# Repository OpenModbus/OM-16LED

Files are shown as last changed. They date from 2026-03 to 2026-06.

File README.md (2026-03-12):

# Open Modbus OM-16LED









A compact industrial-grade **16-channel Modbus RTU LED driver module** featuring high-current MOSFET outputs, per-bank terminal grouping, wide load voltage range, DIN-rail support, and full configuration via Modbus holding registers. Designed for lighting automation, distributed I/O, and custom control applications.

## 1. Product Overview

The **Open Modbus OM-16LED** is a 16-channel low-side LED driver module intended for industrial automation, lighting control, and distributed I/O networks using **Modbus RTU** over RS-485.
It switches DC LED loads such as LED strips, architectural lighting, and indicator arrays up to **60 VDC** at up to **8 A per channel**.

The module combines an **STM32G474** microcontroller, eight **2EDN7534B** dual-channel low-side gate drivers, and sixteen **NTMFS4D0N08XT1G** N-channel power MOSFETs.
This architecture enables reliable, high-current, and scalable LED output control with built-in protection and per-channel MOSFET switching.

### 📦 Hardware Files

The full schematic and BOM are available at:

- Schematic → [https://github.com/OpenModbus/OM-16LED/blob/main/assets/schematics.pdf](https://github.com/OpenModbus/OM-16LED/blob/main/assets/schematics.pdf)
- BOM → [https://github.com/OpenModbus/OM-16LED/blob/main/assets/bom.csv](https://github.com/OpenModbus/OM-16LED/blob/main/assets/bom.csv)

Check the latest release for more!

## 2. Key Features

- 16 low-side MOSFET output channels
- Up to **8 A per channel**, **60 VDC** maximum load voltage
- **12 VDC** direct input or **15–27 VDC** via onboard converter (jumper selectable)
- RS-485 Modbus RTU communication (THVD1450 transceiver)
- Fully configurable serial parameters
- DEGSON 2EDGVC pluggable screw terminals
- DIN-rail mount using **UM72S profile**
- Compact PCB (100 × 72 mm)

## 3. Applications

Ideal for:

- LED strip lighting control
- Architectural and mood lighting
- Building automation
- PLC expansion
- Industrial signaling and indicators
- Stage and display lighting
- Custom distributed lighting networks

## 4. Hardware Architecture

### Microcontroller

The STM32G474RETx MCU handles Modbus RTU processing, configuration storage, and output control logic.
It is an ARM Cortex-M4 running at up to 170 MHz with 512 KB flash and 128 KB RAM, providing ample headroom for advanced output control features.

### Gate Drivers

Eight **2EDN7534B** (Infineon) dual-channel low-side gate drivers control the power MOSFETs.
Their key characteristics include:

- 2 channels per IC (8 ICs → 16 channels total)
- 5 A peak gate drive current
- Precise timing and low output resistance
- Designed for reliable switching of high-current loads

### Output MOSFETs

Sixteen **NTMFS4D0N08XT1G** (onsemi) N-channel MOSFETs perform the actual load switching.
Their key characteristics include:

- 80 V drain-source breakdown voltage
- High continuous drain current
- SO8FL package

### RS-485 Communication

A **THVD1450** (Texas Instruments) transceiver provides differential RS-485 communication with:

- ±18 kV IEC ESD protection
- Fail-safe features
- Suitable for long cable runs

### Power

The board supports two input modes selected by an onboard jumper:

- **15–27 VDC input** — passes through the **R-78E12-1.0** step-down regulator (RECOM), which generates the 12 V gate driver supply
- **12 VDC direct input** — bypasses the 12 V converter; 12 V is fed directly to the gate drivers

In both modes the **R-78E3.3-0.5** step-down regulator (RECOM) generates 3.3 V for the MCU and logic from the main input rail.

## 5. Electrical Specifications

### Supply

- **12 VDC** direct input (jumper: bypass mode) or **15–27 VDC** input (jumper: converter mode)
- Internal regulated **12 V gate drive** supply (converter mode only)
- Internal regulated **3.3 V logic** supply

### Outputs

- 16 low-side MOSFET channels
- Up to **60 VDC** load voltage
- 80 VDC absolute maximum
- **8 A max per channel**
- Channels grouped into **4 banks of 4**

### Communication

- RS-485, 2-wire
- Modbus RTU protocol
- Default settings: **9600 baud, 8N1, address 1**
- All communication parameters can be reconfigured via holding registers

## 6. Mechanical Information

- PCB: **100 × 72 mm**
- DIN-rail enclosure compatibility: **UM72S profile**
- DEGSON 2EDGVC pluggable screw terminals
- Mounting suitable for industrial control cabinets

## 7. Functional Overview

Each output channel is controlled by a per-channel duty cycle value stored in a holding register.
The MCU generates a PWM signal accordingly, driving the gate driver and MOSFET to regulate LED brightness.
A duty cycle of **0** turns the channel fully off; the maximum value drives it fully on.

## 8. Modbus Interface

### Supported Function Codes

> **To be announced soon.**

### Holding Registers

Configuration registers start at **0x00** and are stored in non-volatile memory.

| Register Address (Hex) | Name | Description | Allowed Values | Default |
|---|---|---|---|---|
| 0 (**0x00**) | Slave Address  | Modbus device ID | 1–247 | 1 |
| 1 (**0x01**) | Baud Rate Code | Serial speed selector: **0=1200**, **1=2400**, **2=4800**, **3=9600**, **4=19200**, **5=38400**, **6=57600**, **7=115200** | 0–7 | 3 |
| 2 (**0x02**) | Parity | Communication parity | 0=None, 1=Even, 2=Odd | 0 |
| 3 (**0x03**) | Data Bits | Serial data width | 5–9 (typ. 8) | 8 |
| 4 (**0x04**) | Stop Bits | Serial stop bits | 1–2 | 1 |

### Example Modbus Commands

> **To be announced soon.**

## 9. Wiring

The **OM-16LED** uses low-side (MOSFET) switching.
The module connects the LED load to ground when ON; the load must be powered from your external power supply.

The 16 outputs are grouped into **four banks of 4 channels** (Bank A–D).
This allows one board to drive LED loads powered from different voltages simultaneously.

**Examples**:

- Bank A → 12 V LED strips
- Bank B → 24 V LED strips
- Bank C → 48 V LED channels
- Bank D → 5 V LED indicators

### Low-Side Output Principle

Each output contains a power MOSFET that sinks current:

```text
Load +V  ─────── LED Load ─────── OUTx (SINK)
                                       │
                                       └── GND (OM-16LED)
```

### Recommended Wiring Steps

- Connect the load voltage (up to 60 VDC) to the Vx terminal of the bank.
- Connect the output pin (OUTx) to the negative side of the LED load.
- Tie power supply GND to OM-16LED GND.
- Ensure the supply can support the total current of that bank.

**⚠️ Important Grounding Requirement**:
All load power supplies must share **a common ground** with the OM-16LED.
This is required for the low-side drivers and internal logic to reference the same electrical 0 V.

## 10. Safety Notes

- Do not exceed **60 VDC** load voltage
- Ensure load currents stay within **8 A per channel**
- Maintain proper RS-485 termination and shielding
- Verify adequate heat dissipation when operating at high currents

## 11. Contact & Support

For questions, feedback, or technical assistance regarding the Open Modbus OM-16LED, the following support channels are available:

### 📧 Email Support

For general inquiries, firmware questions, or troubleshooting:
[contact@sszczep.dev](mailto:contact@sszczep.dev)

### 🛠 GitHub Repository

Issue tracker, source code, hardware design files, and community contributions:
[https://github.com/OpenModbus/OM-16LED](https://github.com/OpenModbus/OM-16LED)

### 💬 Open Modbus Discussions

Share projects, ask for help, or suggest features:
[https://github.com/orgs/OpenModbus/discussions](https://github.com/orgs/OpenModbus/discussions)

### 📝 Bug Reports & Feature Requests

Submit issues directly via GitHub Issues:
[https://github.com/OpenModbus/OM-16LED/issues](https://github.com/OpenModbus/OM-16LED/issues)

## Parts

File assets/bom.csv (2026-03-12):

Reference | Value | Footprint | Datasheet | Opis | Qty | Manufacturer | Mouser# | Part Number | LCSC#
C1,C2,C3,C4,C5,C6,C7,C8 | 0.1uF | C_0805_2012Metric | ~ | 0.1 uF 50 VDC 10% 0805 X7R AEC-Q200 | 8 | Murata | 81-GRT21BR71H104KE1L | GRT21BR71H104KE01L | C782178
C13 | 4.7uF | C_0603_1608Metric | ~ | 4.7 uF 25 VDC 10% 0603 X5R | 1 | Murata | 81-GRM188R61E475KE1D | GRM188R61E475KE11D | C90057
C14,C15,C16,C17,C19,C22,C23 | 0.1uF | C_0603_1608Metric | ~ | 0.1 uF 50 VDC 10% 0603 X7R AEC-Q200 | 7 | Murata | 81-GCJ188R71H104KA2D | GCJ188R71H104KA12D | C161115
C18,C21 | 1uF | C_0603_1608Metric | ~ | 1 uF 50 VDC 10% 0603 X5R AEC-Q200 | 2 | Murata | 81-GRT188R61H105KE3D | GRT188R61H105KE13D | C126631
C20 | 10nF | C_0603_1608Metric | ~ | 0.01 uF 50 VDC 10% 0603 X7R AEC-Q200 | 1 | Murata | 81-GCM188R71H103KA7D | GCM188R71H103KA37D | C85863
C9,C10,C11,C12 | 10uF | C_1206_3216Metric | ~ | 10 uF 50 VDC 10% 1206 X5R AEC-Q200 | 4 | Murata | 81-GRT31CR61H106KE1L | GRT31CR61H106KE01L | C417124
D1 | CD123D-B140LR | D_SOD-123 | https://www.mouser.com/catalog/specsheets/bourns_CD123D-B1xR.pdf | Schottky diode, small symbol | 1 | Bourns | 652-CD123D-B140LR | CD123D-B140LR | C6877135
D2 | SMAJ28A | D_SMA | https://www.littelfuse.com/media?itemid=75e32973-b177-4ee3-a0ff-cedaf1abdb93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 | 400W unidirectional Transient Voltage Suppressor, 28.0Vr, SMA(DO-214AC) | 1 | Littelfuse | 576-SMAJ28A | SMAJ28A | C148227
D3 | SM712_SOT23 | SOT-23 | https://www.littelfuse.com/~/media/electronics/datasheets/tvs_diode_arrays/littelfuse_tvs_diode_array_sm712_datasheet.pdf.pdf | 7V/12V, 600W Asymmetrical TVS Diode Array, SOT-23 | 1 | Littelfuse | 576-SM712-02HTG | SM712-02HTG | C172881
D4,D5 | RED | LED_0603_1608Metric | ~ | Single Color LEDs Red Clear 621nm | 2 | LITEON | 859-LTST-C190EKT | LTST-C190EKT | C364560
F1,F2,F3,F4,F5,F6,F7,F8,F9,F10,F11,F12,F13,F14,F15,F16 | 8A 60VDC | Fuse_0679H | https://www.belfuse.com/media/datasheets/products/circuit-protection/ds-cp-0679h-series.pdf | Surface Mount Fuse 8A 350 VAC 72 VCD | 16 | Bel Fuse | 530-0679H8000-05 | 0679H8000-05 | C3156889
F17 | 1A | Fuse_1206_3216Metric | https://www.littelfuse.com/assetdocs/littelfuse_fuse_466_datasheet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 | Surface Mount Fuse 63V FA 1206 1A VFA Slimline | 1 | Littelfuse | 576-0466001.NR | 0466001.NR | C151135
J1 | 2EDGVC-5.0-04P | TerminalBlock_DEGSON_2EDGVC-5.0-04P_No_SilkScreen |  |  | 1 | DEGSON |  | 10030002303 | C441377
J2,J3,J4,J5 | 2EDGVC-5.0-06P | TerminalBlock_DEGSON_2EDGVC-5.0-06P_No_SilkScreen |  |  | 4 | DEGSON |  | 10030002306 | C441379
J6 | 02x03 1.27 | PinHeader_2x03_P1.27mm_Vertical | ~ | Generic connector, double row, 02x03, odd/even pin numbering scheme (row 1 odd numbers, row 2 even numbers), script generated (kicad-library-utils/schlib/autogen/connector/) | 1
Q1,Q2,Q3,Q4,Q5,Q6,Q7,Q8,Q9,Q10,Q11,Q12,Q13,Q14,Q15,Q16 | NTMFS4D0N08X | ONSemi_SO-8FL_488AA | https://www.onsemi.com/download/data-sheet/pdf/ntmfs4d0n08x-d.pdf | MOSFETs T10 80V STD NCH MOSFET SO8FL | 16 | onsemi | 863-NTMFS4D0N08XT1G | NTMFS4D0N08XT1G | C35185549
R1,R2,R3,R4,R5,R6,R7,R8,R9,R10,R11,R12,R13,R14,R15,R16 | 10 | R_0603_1608Metric | ~ | SMD 0603 10Ohm 1% AEC-Q200 | 16 | Panasonic | 667-ERJ-H3EF10R0V | ERJ-H3EF10R0V | C2842424
R17 | 10K | R_0603_1608Metric | ~ | SMD 0603 10KOhm 1% 1/8W AEC-Q200 | 1 | Panasonic | 667-ERJ-H3EF1002V | ERJ-H3EF1002V | C4297913
R18 | 2K2 | R_0603_1608Metric | ~ | SMD 0603 2K2 Ohm 5% 1/4W AEC-Q200 | 1 | Panasonic | 667-ERJ-UP3J222V | ERJ-UP3J222V | C491201
R19 | 470 | R_0603_1608Metric | ~ | SMD 0603 470Ohm 5% 1/4W AEC-Q200 | 1 | Panasonic | 667-ERJ-UP3J471V | ERJ-UP3J471V | C491199
U1 | STM32G474RETx | LQFP-64_10x10mm_P0.5mm | https://www.st.com/resource/en/datasheet/stm32g474re.pdf | ARM Microcontrollers - MCU Mainstream Arm Cortex-M4 MCU 170 MHz 512 Kbytes of Flash Math Accel, HR Timer | 1 | STMicroelectronics | 511-STM32G474RET6 | STM32G474RET6 | C521608
U10 | R-78E12-1.0 | Converter_DCDC_RECOM_R-78E-0.5_THT | https://www.mouser.pl/datasheet/3/887/1/R-78E-1.0.pdf | 1.0 AStep-Down DC/DC-Regulator, 15-27V input, 12V fixed Output Voltage, LM78xx replacement, -40°C to +85°C, SIP3 | 1 | RECOM | 919-R-78E12-1.0/X9 | R-78E12-1.0/X9 | C5240945
U11 | R-78E3.3-0.5 | Converter_DCDC_RECOM_R-78E-0.5_THT | https://www.recom-power.com/pdf/Innoline/R-78Exx-0.5.pdf | 0.5A Step-Down DC/DC-Regulator, 6-28V input, 3.3V fixed Output Voltage, LM78xx replacement, -40°C to +85°C, SIP3 | 1 | RECOM | 919-R-78E3.3-0.5 | R-78E3.3-0.5 | C18212316
U12 | THVD1450DR | VSON-8-1EP_3x3mm_P0.65mm_EP1.6x2.4mm | https://www.ti.com/lit/ds/symlink/thvd1450.pdf | 3.3-V to 5-V RS-485 transceiver with ±18-kV IEC ESD protection, VSON-8 | 1 | Texas Instruments | 595-THVD1450DRBR | THVD1450DRBR | C1850226
U2,U3,U4,U5,U6,U7,U8,U9 | 2EDN7534B | SOT-23-6 | https://www.mouser.pl/datasheet/3/70/1/Infineon_2EDN7534B_DataSheet_v01_00_EN.pdf | Dual-channel low-side 5 A gate driver ICs with low output resistance and excellent timing accuracy | 8 | Infineon Technologies | 726-2EDN7534BXTSA1 | 2EDN7534BXTSA1 | C3654924

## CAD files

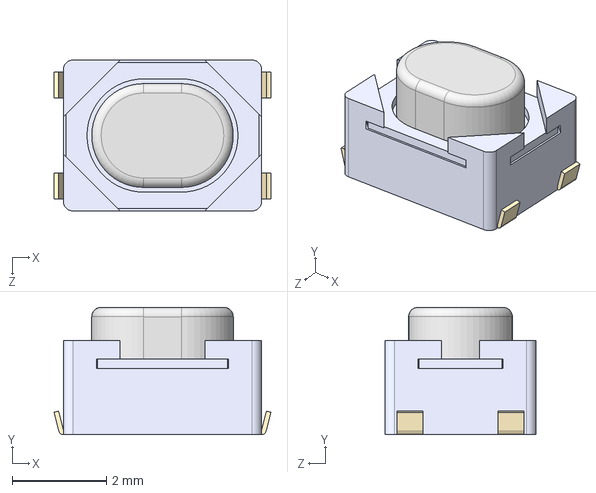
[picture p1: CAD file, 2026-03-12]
kicad/3D/PTS810SJM250SMTR LFS.STEP
4.60 x 2.70 x 3.20 mm

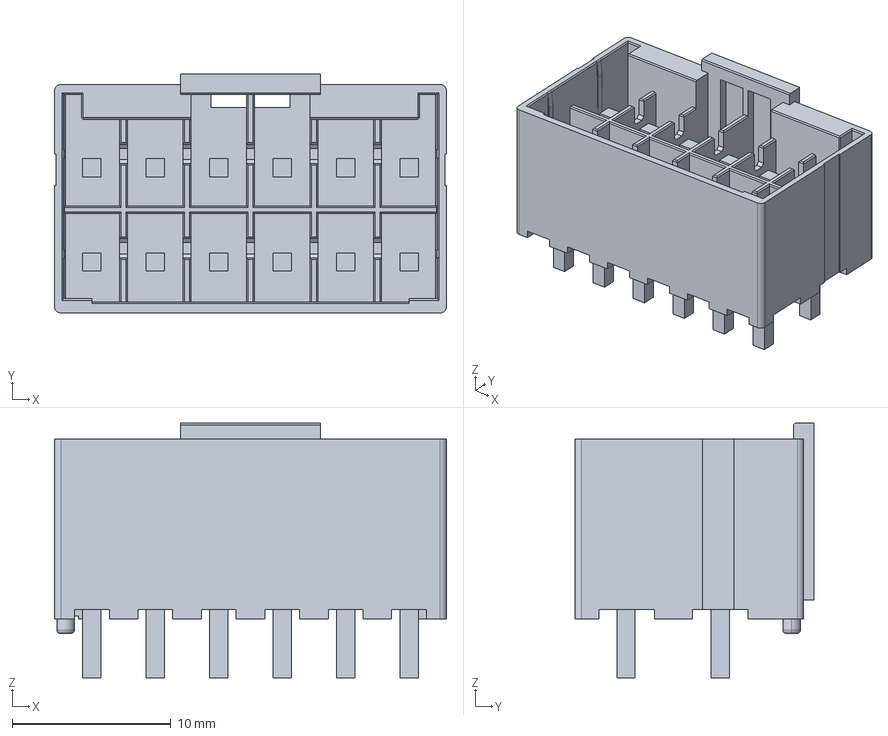
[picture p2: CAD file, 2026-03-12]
kicad/3D/1-2423324-2.stp
24.7 x 15.1 x 16.1 mm

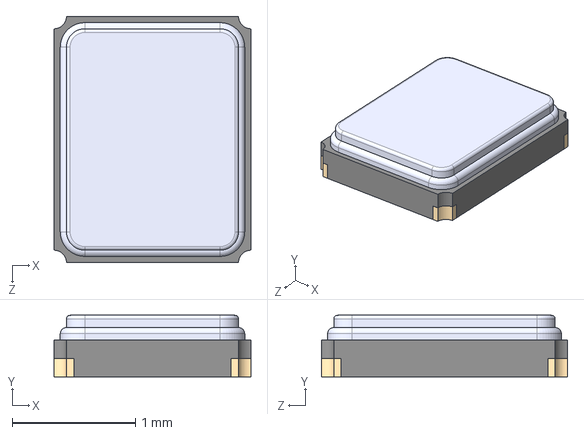
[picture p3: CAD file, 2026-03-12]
kicad/3D/NX2016SA-24MHZ-EXS00A-CS10820.STEP
1.60 x 0.5 x 2.00 mm

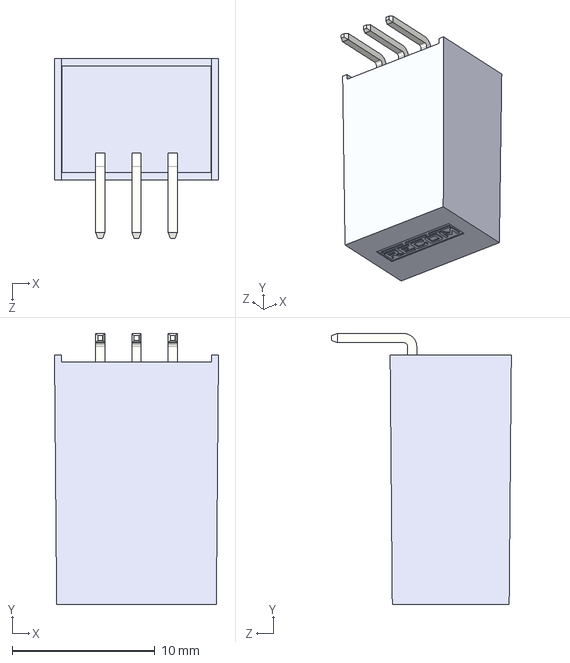
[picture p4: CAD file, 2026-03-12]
kicad/3D/R-78K-2.0L.stp
11.5 x 19.0 x 12.6 mm

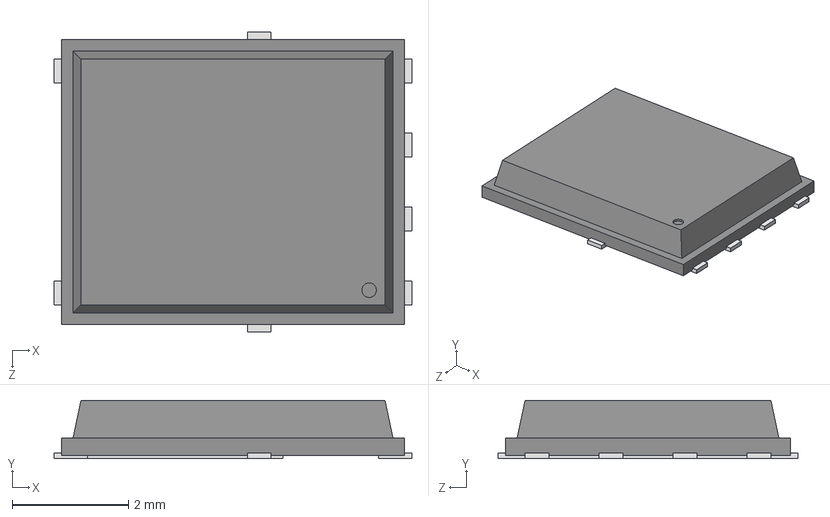
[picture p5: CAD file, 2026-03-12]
kicad/3D/NTMFS4D0N08XT1G.stp
6.15 x 1 x 5.15 mm

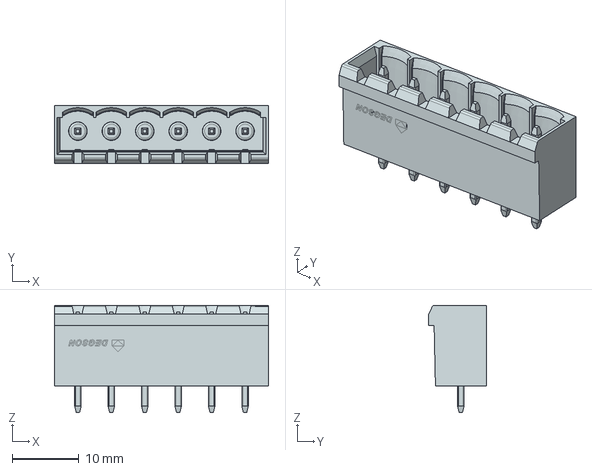
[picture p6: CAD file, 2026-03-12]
kicad/3D/2EDGVC-5.0-06P-1Y-100Z(H).stp
32.0 x 8.60 x 16.0 mm

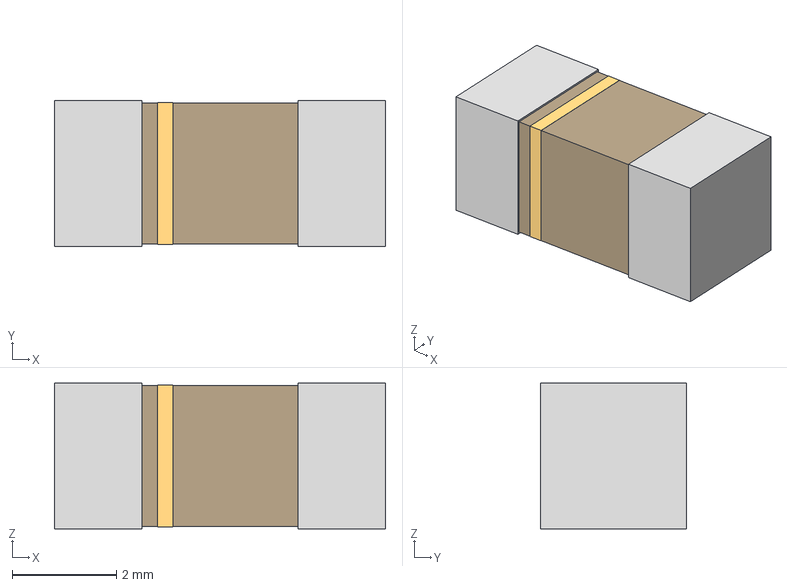
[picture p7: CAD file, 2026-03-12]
kicad/3D/FUSE_0679H_BEL.step
6.35 x 2.79 x 2.79 mm

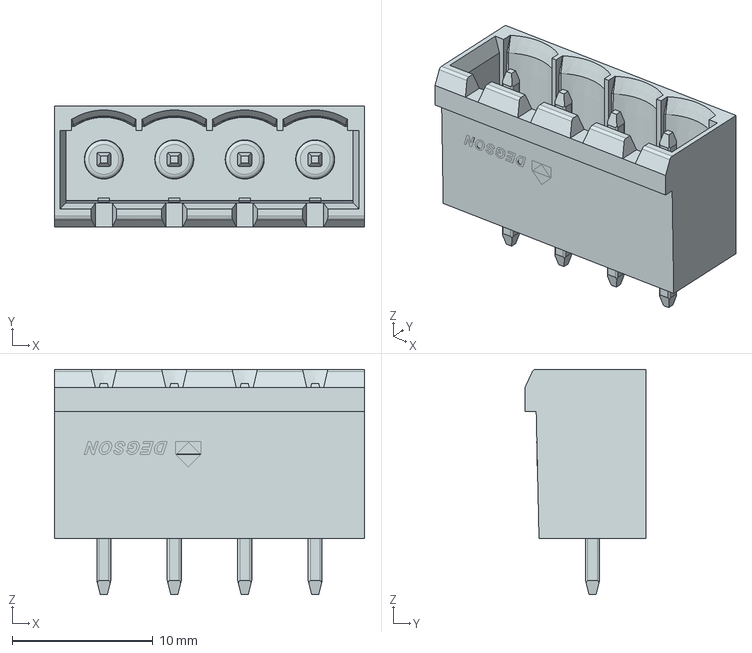
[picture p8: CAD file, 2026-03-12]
kicad/3D/2EDGVC-5.0-04P-1Y-100Z(H).stp
22.0 x 8.60 x 16.0 mm

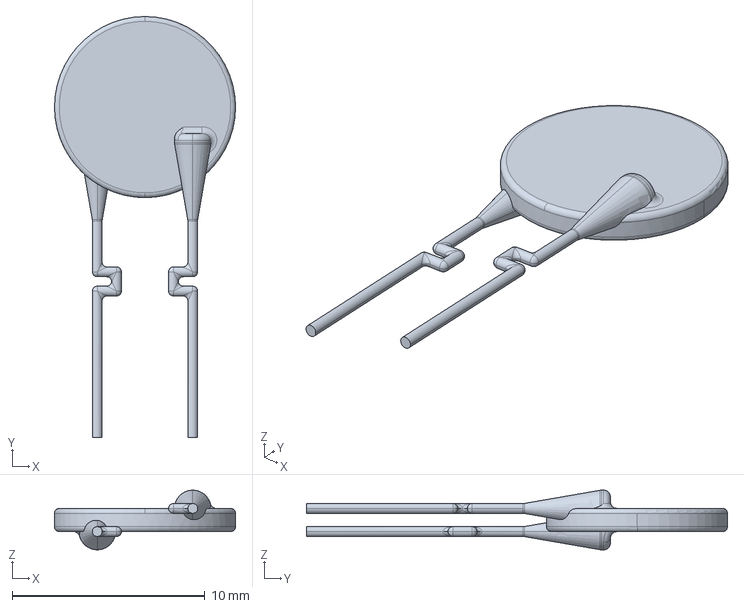
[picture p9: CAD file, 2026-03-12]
kicad/3D/MF-RHT200.stp
9.40 x 21.9 x 3.10 mm

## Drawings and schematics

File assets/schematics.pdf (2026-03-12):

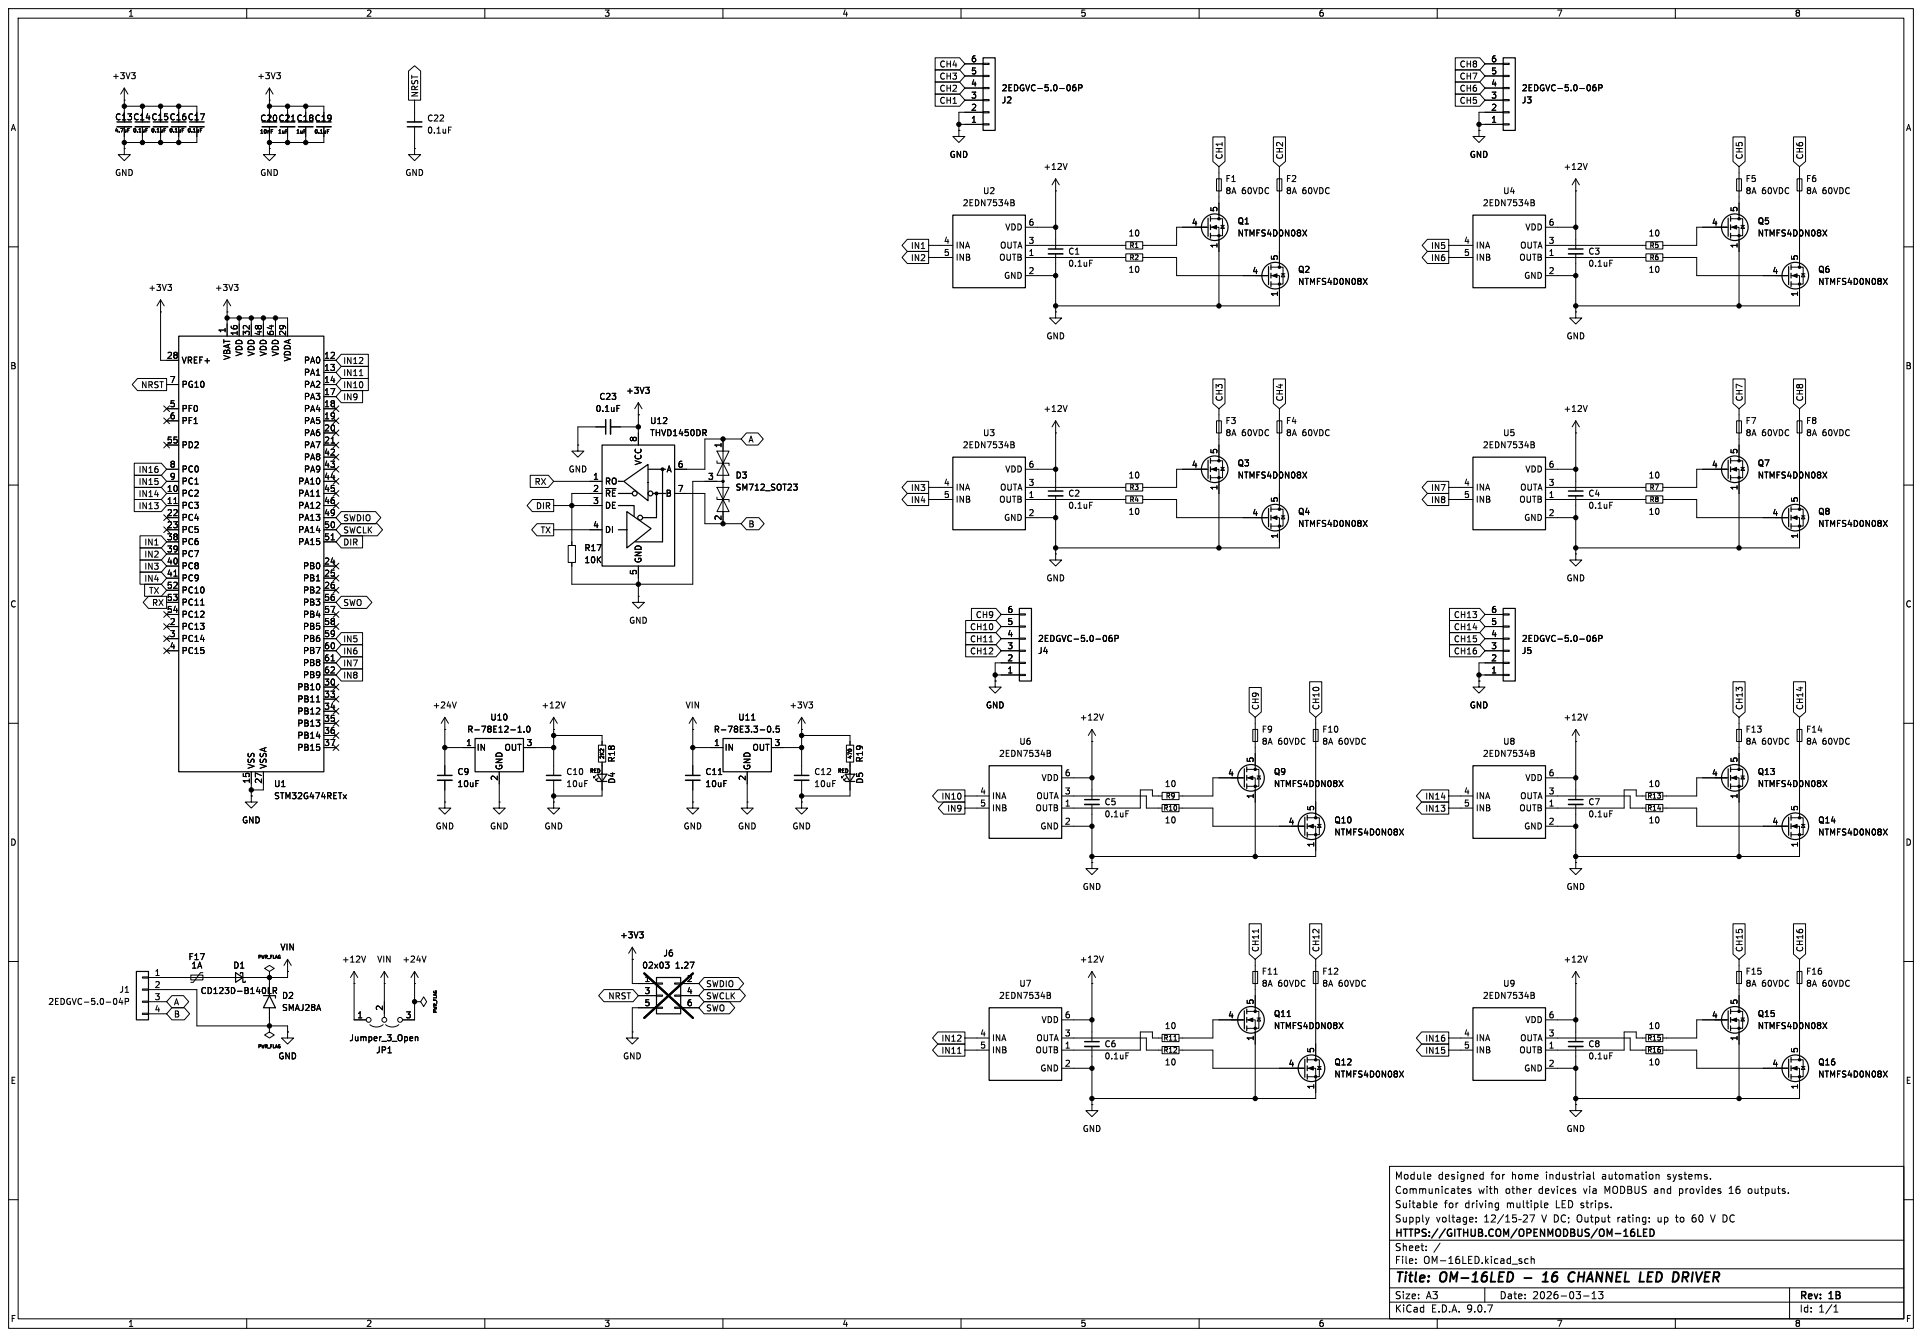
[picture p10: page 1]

1 VDD 16 VDD 32 VSS 15 VDD 48 VSSA 27 VDD 64 VDDA 29 PA0 12 PA1 13 PA2 14 PA3 17 PA4 18 PA5 19 PA6 20 PA7 21 PA8 42 PA9 43 PA10 44 PA11 45 PA12 46 PA13 49 PA14 50 PA15 51 PB0 24 PB1 25 PB2 26 PB3 56 PB4 57 PB5 58 PB6 59 PB7 60 PB8 61 PB9 62 PB10 30 PB11 33 PB12 34 PB13 35 PB14 36 PB15 37 U1STM32G474RETx 4

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

File: OM-16LED.kicad_sch Sheet: / HTTPS://GITHUB.COM/OPENMODBUS/OM-16LED

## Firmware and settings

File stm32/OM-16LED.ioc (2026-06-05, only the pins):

Mcu.UserName=STM32G474RETx
PA0.GPIO_Label=CH12
PA0.Signal=S_TIM2_CH1
PA1.GPIO_Label=CH11
PA1.Signal=S_TIM2_CH2
PA15.GPIO_Label=DIR
PA15.Signal=GPIO_Output
PA2.GPIO_Label=CH10
PA2.Signal=S_TIM2_CH3
PA3.GPIO_Label=CH9
PA3.Signal=S_TIM2_CH4
PB6.GPIO_Label=CH5
PB6.Signal=S_TIM4_CH1
PB7.GPIO_Label=CH6
PB7.Signal=S_TIM4_CH2
PB8-BOOT0.GPIO_Label=CH7
PB8-BOOT0.Signal=S_TIM4_CH3
PB9.GPIO_Label=CH8
PB9.Signal=S_TIM4_CH4
PC0.GPIO_Label=CH16
PC0.Signal=S_TIM1_CH1
PC1.GPIO_Label=CH15
PC1.Signal=S_TIM1_CH2
PC10.GPIO_Label=TX
PC10.Signal=UART4_TX
PC11.GPIO_Label=RX
PC11.Signal=UART4_RX
PC2.GPIO_Label=CH14
PC2.Signal=S_TIM1_CH3
PC3.GPIO_Label=CH13
PC3.Signal=S_TIM1_CH4
PC6.GPIO_Label=CH1
PC6.Signal=S_TIM3_CH1
PC7.GPIO_Label=CH2
PC7.Signal=S_TIM3_CH2
PC8.GPIO_Label=CH3
PC8.Signal=S_TIM3_CH3
PC9.GPIO_Label=CH4
PC9.Signal=S_TIM3_CH4

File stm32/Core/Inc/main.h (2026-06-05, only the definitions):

#define CH16_Pin GPIO_PIN_0
#define CH16_GPIO_Port GPIOC
#define CH15_Pin GPIO_PIN_1
#define CH15_GPIO_Port GPIOC
#define CH14_Pin GPIO_PIN_2
#define CH14_GPIO_Port GPIOC
#define CH13_Pin GPIO_PIN_3
#define CH13_GPIO_Port GPIOC
#define CH12_Pin GPIO_PIN_0
#define CH12_GPIO_Port GPIOA
#define CH11_Pin GPIO_PIN_1
#define CH11_GPIO_Port GPIOA
#define CH10_Pin GPIO_PIN_2
#define CH10_GPIO_Port GPIOA
#define CH9_Pin GPIO_PIN_3
#define CH9_GPIO_Port GPIOA
#define CH1_Pin GPIO_PIN_6
#define CH1_GPIO_Port GPIOC
#define CH2_Pin GPIO_PIN_7
#define CH2_GPIO_Port GPIOC
#define CH3_Pin GPIO_PIN_8
#define CH3_GPIO_Port GPIOC
#define CH4_Pin GPIO_PIN_9
#define CH4_GPIO_Port GPIOC
#define DIR_Pin GPIO_PIN_15
#define DIR_GPIO_Port GPIOA
#define TX_Pin GPIO_PIN_10
#define TX_GPIO_Port GPIOC
#define RX_Pin GPIO_PIN_11
#define RX_GPIO_Port GPIOC
#define CH5_Pin GPIO_PIN_6
#define CH5_GPIO_Port GPIOB
#define CH6_Pin GPIO_PIN_7
#define CH6_GPIO_Port GPIOB
#define CH7_Pin GPIO_PIN_8
#define CH7_GPIO_Port GPIOB
#define CH8_Pin GPIO_PIN_9
#define CH8_GPIO_Port GPIOB

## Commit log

2026-03-12 feat: board design
    [1-2423324-2.stp, 2EDGVC-5.0-04P-1Y-100Z(H).stp, 2EDGVC-5.0-06P-1Y-100Z(H).stp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]
2026-03-12 feat: add bom and schematics
    [bom.csv]
2026-03-13 feat: rotate 3d models, fix trace width
2026-06-05 feat: add stm32 code

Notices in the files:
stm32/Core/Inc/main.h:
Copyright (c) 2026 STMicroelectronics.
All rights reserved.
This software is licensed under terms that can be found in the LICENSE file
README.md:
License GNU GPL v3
